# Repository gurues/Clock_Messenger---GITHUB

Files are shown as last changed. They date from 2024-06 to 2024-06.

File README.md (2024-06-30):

# CLOCK MESSENGER

## Descripción y funcionamiento

Clock Messenger es un pequeño proyecto que mediante un Wemos D1 mini, una matriz led MAX-7219 FC-16 y un buzzer se crea un dispositivo que mostrará la hora y mensajes básicos repetitivos de fecha y tiempo de la ciudad a elección. También se crea una app en Blynk 2.0 para controlar el dispositivo así como para enviar mensajes instantaneos, repetitivos o programados además de alarma sonora.

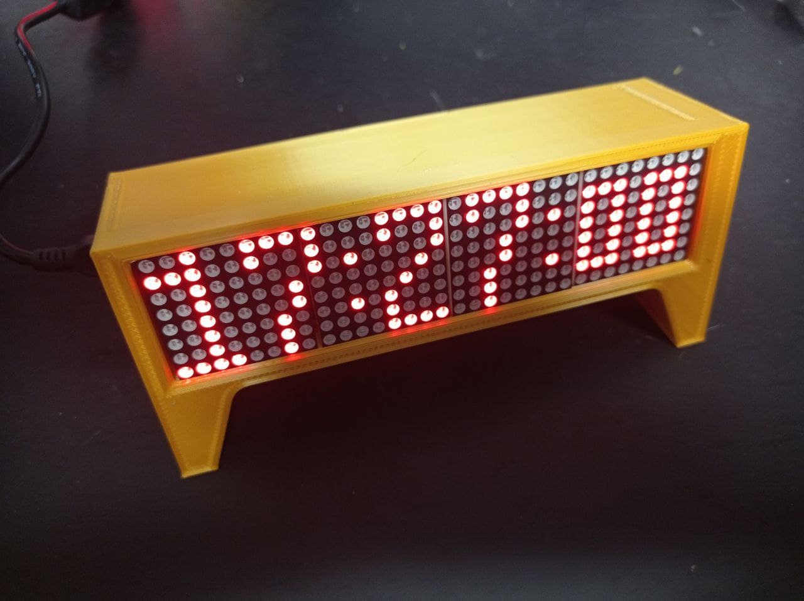
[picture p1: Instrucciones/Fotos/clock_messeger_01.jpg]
Clock Messenger


Debido a las restricciones de Blynk 2.0 (solo 5 DataStream en su versión libre) utilizaremos un terminal y una serie de comandos para configurar y controlar el Clock Messenger

Por lo tanto debes tener cuenta en Blynk y OpenWeatherMap para actualizar los siguientes parámetros:

main.cpp

```Arduino

// Actualizar con tus datos de BLYNK
#define BLYNK_TEMPLATE_ID "XXXXXXXXXXXXXXXXXX"
#define BLYNK_TEMPLATE_NAME "ClockMessenger"
#define BLYNK_AUTH_TOKEN "XXXXXXXXXXXXXXXXXXX"
```

configuracion.h

```Arduino
// Datos OpenWeatherMap
String hostOpenWeatherMap = "http://api.openweathermap.org/data/2.5/weather";

String apiKey = "XXXXXXXXXXXXXXXXXXXXXXXXXXXXX"; // Sustituye por tu API Key
String idCiudad = "XXXXXXXXXXXXX"; // Sustituye por el id de tu ciudad -> EJEMPLO: Cambrils = 3126888 Reus = 3111933.
```

Los mensajes tratados son:

* Mensajes de reloj. Muestran la hora en pantalla.
* Mensajes básicos. Muestras el tiempo de la ciudad configurada, día y fecha actual.
* Mensajes instantaneos. Enviados por la app de control.
* Mensajes repetitivos. Enviados y configurados por la app de control.
* Mensajes programados. Enviados y configurados por la app de control.

Para la configuración de los mensajes, estos deben comenzar de una forma determinada:

* Mensajes instantaneos: Deben comenzar por el caracter @. Ej: @Hola Mundo. Esto mostrará en la pantalla del reloj el mensaje Hola Mundo.
* Mensajes Repetitivos: Deben comenzar por el caracter R@. Ej: R@Hola Mundo. Esto mostrará en la pantalla del reloj el mensaje Hola Mundo de forma repetitiva
* Mensajes Programados: Deben comenzar por el caracter P@. Ej: P@Hola Mundo. Esto mostrará en la pantalla del reloj el mensaje Hola Mundo a la hora programada.

Disponemos de una serie de comandos que nos ayudaran configurar el dispositivo:

* Comando /MENSAJES/: Muestra los Mensajes Repetitivos y Programados configurados.
* Comando /HELP/: Muestra la Ayuda de comandos.
* Comando /parametro=: El numero después del = se configura como valor del parametro (ej: /offset=-3.5)
* Comando /parametro/: Muestra el valor actual del parametro de control (ej: /offset/)
* Comando /rep_min=: Configura los mensajes se repiten cada x minutos
* Comando /prog_h:min=: Configura hora del mensaje programado o de la alarma 1
* Comando /prog_h:min_2=: Configura hora de la alarma 2
* Comando /sonido=: Activa/Desactiva (1/0) mensajes con alerta sonora
* Comando /alarma=: Activada/Desactivada (1/0) Alarma sonora en Clock_Messenger
* Comando /offset=: Configura el offset de temperatura (ej: /OFFSET=-3.5)
* Comando /ESTADO/: Muestra el estado de los parametros de control Clock_Messenger
* Comando /CLEAR/: Limpia Terminal y vacia mensajes Repetitivos y Programados
  
Tanto los mensajes como los comandos se introduciran a través de la terninal de la aplicación de control del reloj (Blynk 2.0).

DataStream App control Clock Messenger (Blynk 2.0):

* V0. Control de tiempo del mensaje rodante en la pantalla (0 a 300 seg)
* V1. Terminal de control para la configuracón del Clock Messenger mediante comandos y mensajes.
* V2. Control de los mensajes programados (permisivo para la ejecución de mensajes programados)
* V3. Control de los mensajes repetitivos (permisivo para la ejecución de mensajes repetitivos)
* V4. Muestra en el Terminal todos los comandos de configuración del Clock Messenger

El funcionamiento de los mensajes es el siguiente:

* La priorida de los mensajes se determina por el orden de entrada o configuración. El último en entrar o configurarse es el que se muestra en pantalla y por lo tanto el más prioritario. Por eso los mensajes instantaneos son los más prioritarios. Respecto a la prioridad entre los mensajes repetitivos y programados se respeta la misma condición anterior, el último en entrar o configurarse se muestra en pantalla.

* Los mensajes de reloj y datos básicos son los menos prioritarios, siempre se detienen ante la llegada de los otros tipos de mensajes.

* Los mensajes se suceden a través de una serie de funciones hasta que se muestran en pantalla. El flujo de los mensajes y funciones se detalla a continuación:

```text
      retardo_messege() => Configura el tiempo total del mensaje en pantalla.

      send_message() => Envia y muestra el mensaje por pantalla.

      programador() => Controla retorno tras mostrar mensaje y activa las funciones de Clock 
                       y datos básicos.

      clock_send() => Muestra el reloj en pantalla.

      obtenerDatosBasicos() => Obtiene los datos básicos.

      envio_mensaje_rep() => Control de mensajes repetitivos.
```

* Flujo de mensajes instantaneos. Es el mensaje con mayor prioridad, detiene y muestra este mensaje en
  cuanto llegue frente a cualquier otro.

```text
      message = true ==>retardo_messege() -->send_message() -->programador()--> clock_send()

                                                                        |--> obtenerDatosBasicos()
```
  
* Flujo de mensajes programados. Son mensaje prioritarios al reloj y a los datos básicos. Si coinciden en el
  tiempo con estos se detienen y se mostraran los mensajes repetitivos.

```text
control_prog == 1(se cumple hh:mm) ==>retardo_messege() -->send_message() 
                                    
                                                             -->programador() -->clock_send()

                                                                        |--> obtenerDatosBasicos()
```

* Flujo de mensajes repetitivos. Son mensaje prioritarios al reloj y a los datos básicos. Si coinciden en el
  tiempo con estos se detienen y se mostraran los mensajes repetitivos.

```text
se programa tiempo repetición ==>envio_mensaje_rep() -->send_message() 
      
                                                            -->programador() -->clock_send()

                                                                        |--> obtenerDatosBasicos()
```

* El reloj se trata como si fuera un mensaje. Los mensajes de reloj son los menos prioritario.

```text
      clock_send() ==> Se ejecuta cada 1 seg para mostrar el reloj si no hay mensaje que mostrar

```

* Los mensajes de datos basicos se muestran de forma repetida y son los menos prioritarios junto al reloj.

```text  
obtenerDatosBasicos() ==> Se ejecuta cada 95 seg para mostrar el tiempo de la cuidad,el día y la fecha.

```

## Material necesario

* Wemos D1 Mini o ESP8266 NodeMCU.
* Matriz led MAX-7219 FC-16.
* Buzzer activo.
* Resistencia 220 ohm, transistor NPN y diodo (material opcional -> circuito para el contol del Buzzer).
* RTC DS3231 (opcional, solo si no se dispone de conexión permanete a internet).

## Instrucciones

La carpeta instrucciones hay una serie de guias y archivos que son de utilidad para realizar el proyecto.

* Carpeta 3D: Archivos STL o 3MF para la impresión de la caja del reloj.
* Carpeta Blynk: App de control de Clock Messenger.
* Carpeta Conexiones: Esquemas de conexiones del proyecto.
* Carpeta Fotos: Fotos del resultado final.

### No he encontrado el porque pero en unos 7 dias es necesario realizar un reset del reloj para que vuelva funcionar si utilizamos RTC. En tiendo que es un desbordamiento de algún registro pero no lo he podido solucionar. En la parte superior del reloj hay un agujero para que mediante un clip podamos acceder al reset del dispositivo
  
### Realizado por gurues@2024 (<ogurues@gmail.com>)

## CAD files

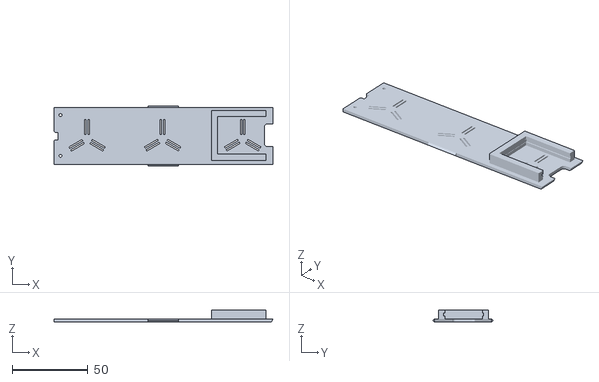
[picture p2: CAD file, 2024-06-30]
Instrucciones/3D/Box_Tapa_Clock_Messenger_WEMOS.stl
145.0 x 39.9 x 8.00

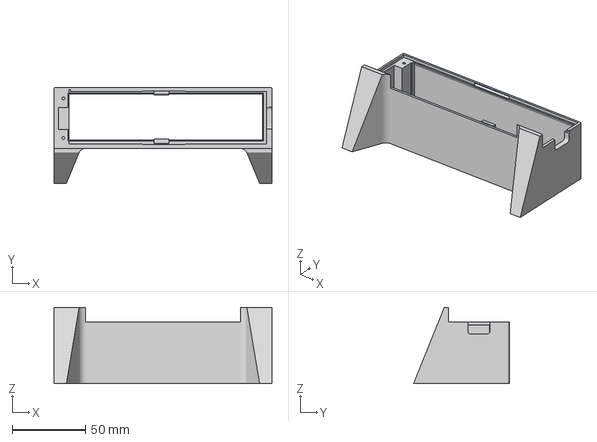
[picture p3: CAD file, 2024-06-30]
Instrucciones/3D/Box_Clock_Messenger.3mf
148.4 x 65.4 x 52.0 mm

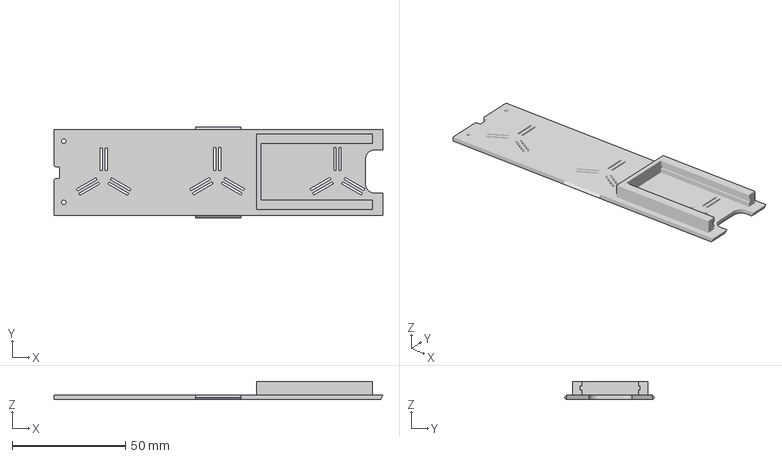
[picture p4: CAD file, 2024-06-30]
Instrucciones/3D/Box_Tapa_Clock_Messenger_ESP8266.3mf
145.0 x 39.9 x 8.00 mm

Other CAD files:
Instrucciones/3D/Caja_Clock_Messenger.3mf
Instrucciones/3D/Tapa_Clock_Messenger.3mf

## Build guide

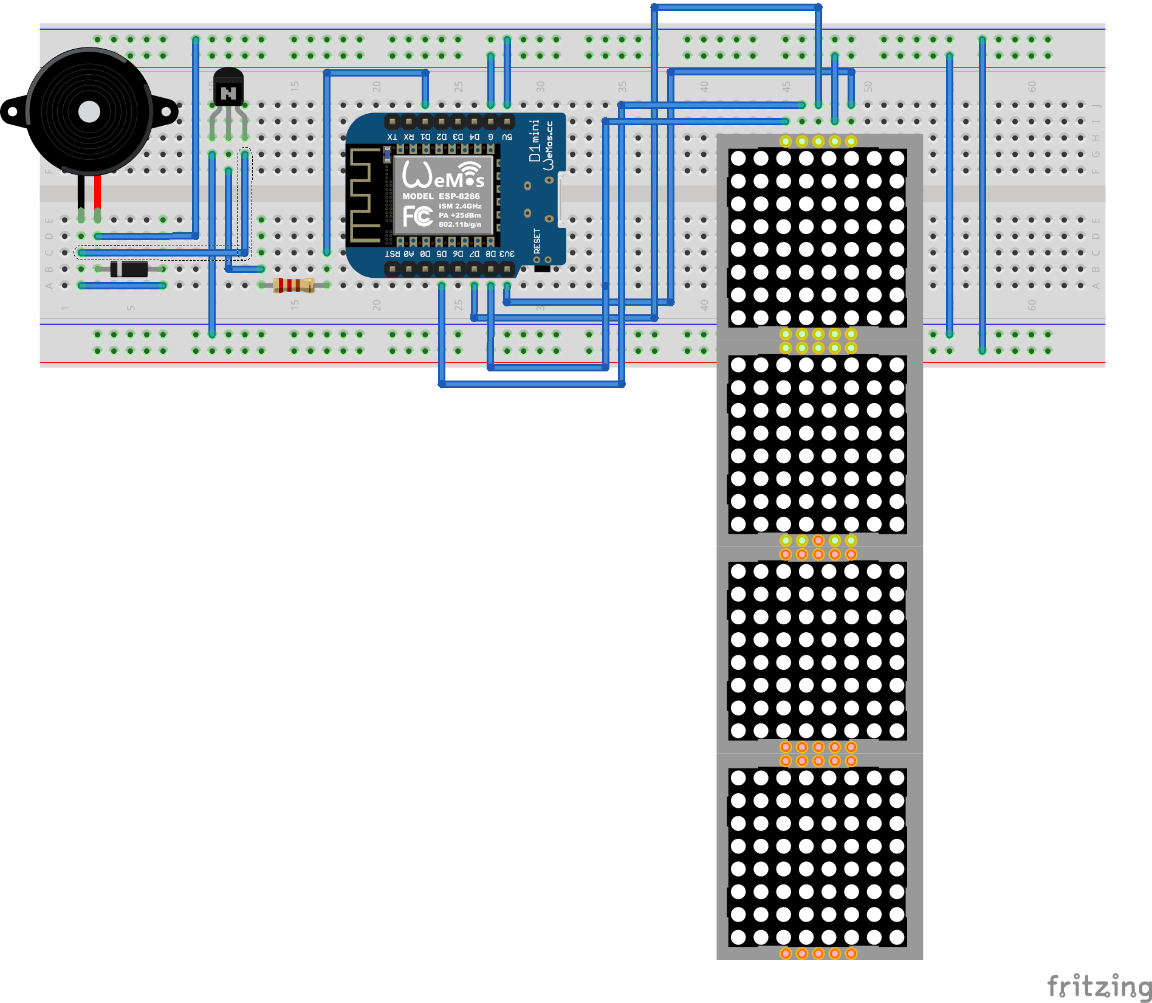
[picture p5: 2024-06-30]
Instrucciones/Conexiones/Clock_Messenger.png

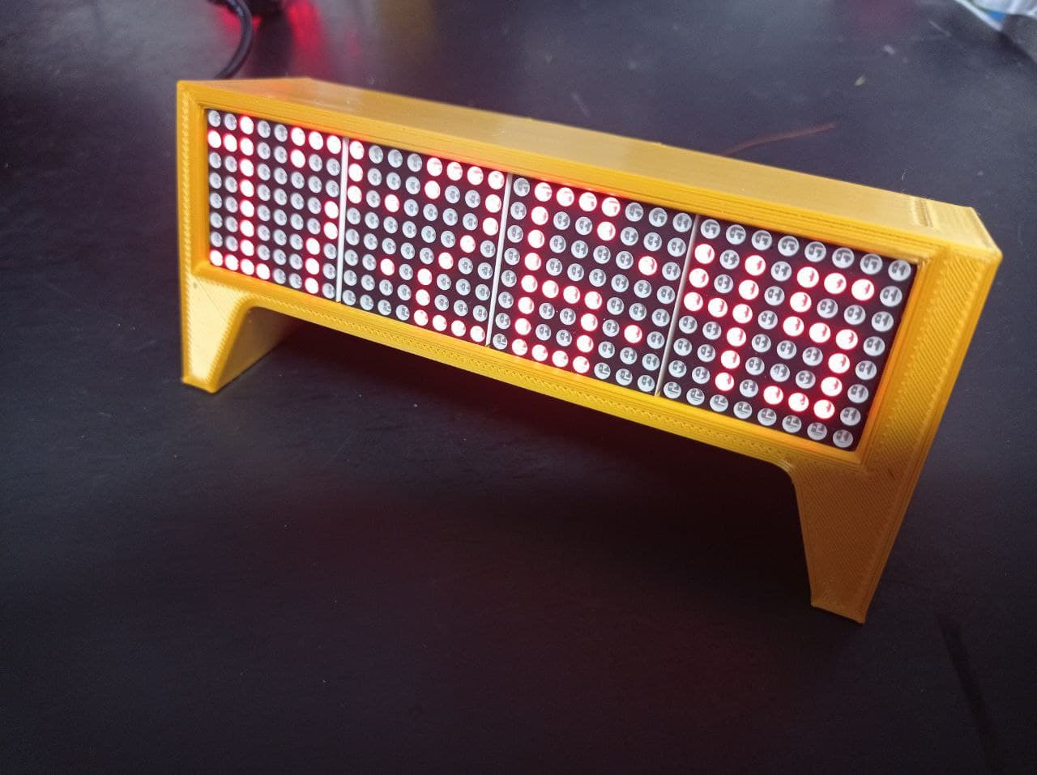
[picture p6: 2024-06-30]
Instrucciones/Fotos/clock_messeger_02.jpg

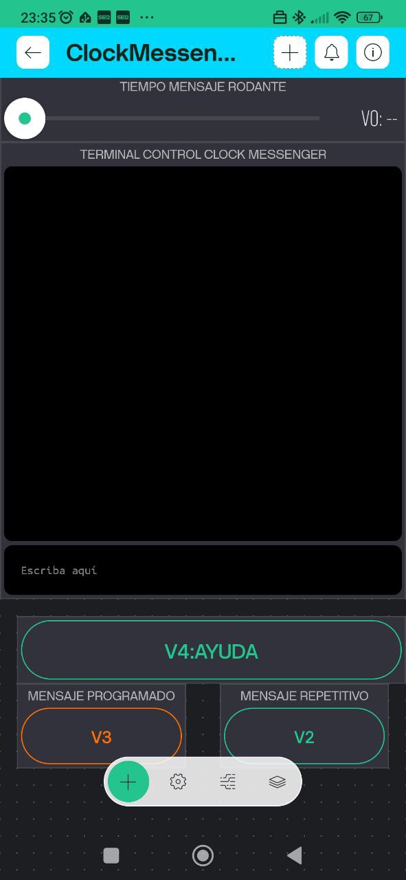
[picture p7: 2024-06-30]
Instrucciones/Blynk/app_1.jpg

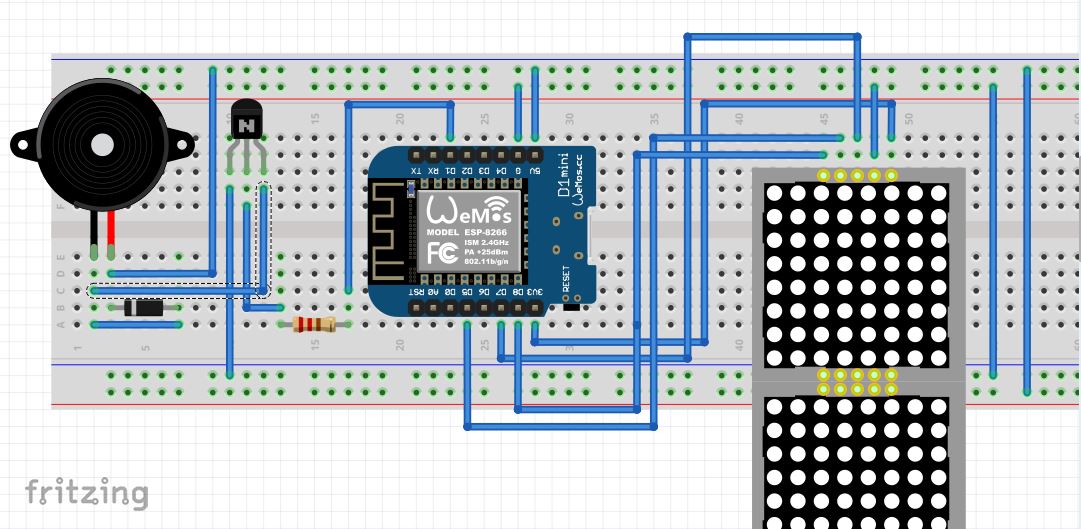
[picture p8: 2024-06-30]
Instrucciones/Conexiones/Conexiones Clock Messenger.JPG

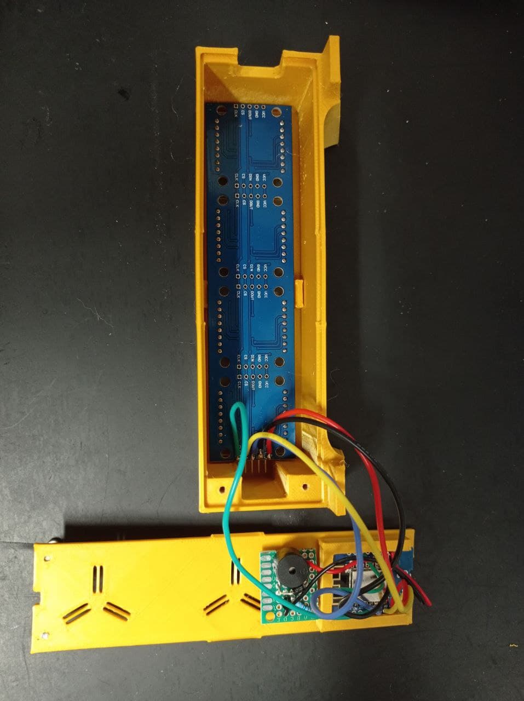
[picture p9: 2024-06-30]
Instrucciones/Fotos/clock_messeger_03.jpg

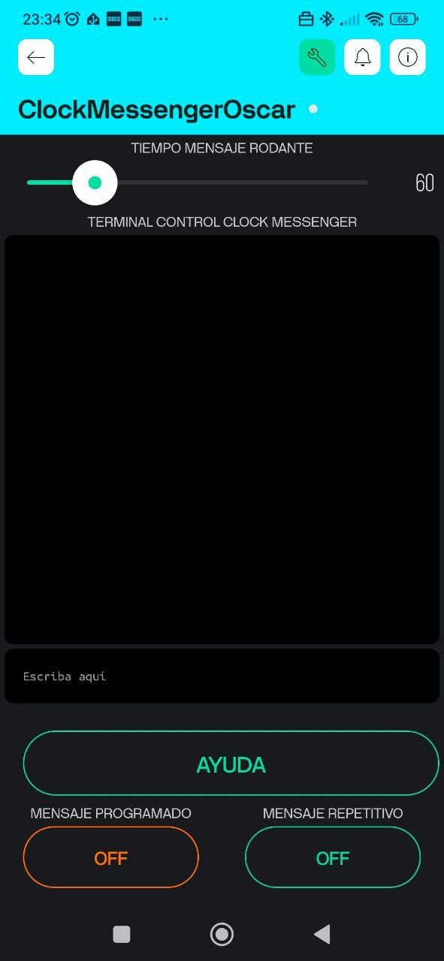
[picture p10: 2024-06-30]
Instrucciones/Blynk/app_2.jpg

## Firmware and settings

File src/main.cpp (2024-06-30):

/*  Realizdo por gurues@3DO 
-----------------------------------------------------------------------------------------------------------
-------------------------------         CLOCK MESSENGER         -------------------------------------------
-----------------------------------------------------------------------------------------------------------

  Mediante un Wemos D1 mini y una matriz led MAX-7219 FC-16 se realiza un dispositivo que mostrará la hora y
  mensajes básicos repetitivos de fecha y tiempo de la ciudad a elección. También se crea una app en Blynk
  para controlar el dispositivo así como para enviar mensajes instantaneos, repetitivos o programados. Solo
  con 5 DataStreams (restricción de Blynk)

***********************************************************************************************************
-- CONEXIÓN HARDWARE (Wemos D1 mini o ESP8266 <--> FC16):
-- 3V <--> VCC, GND <--> GND, D7 <--> DIN, D8 <--> CS, D5 <--> CLK
-- CONEXIÓN HARDWARE (Wemos D1 mini o ESP8266 <--> BUZZER):
-- D1 <--> - , GND, GND
-- Otra forma de conexión es mediante un transistor NPN
-- D1 Wemos/ESP <--> R1= 220 ohm, R1 <--> Base NPN, Emisor NPN <--> GND Wemos/ESP, Colector NPN <--> - Buzzer
-- + Buzzer <--> 5v Wemos/ESP, + diodo <--> - Buzzer, - diodo <--> + Buzzer
-- CONEXIÓN HARDWARE (Wemos D1 mini o ESP8266 <--> RTC -> DS3231):
-- D2, D3 <--> RTC -> DS3231 (si no disponemos conexión permanente a internet)
***********************************************************************************************************

*/

// Actualizar con tus datos de BLYNK
#define BLYNK_TEMPLATE_ID "XXXXXXXXXXXXXXXXXX"
#define BLYNK_TEMPLATE_NAME "ClockMessenger"
#define BLYNK_AUTH_TOKEN "XXXXXXXXXXXXXXXXXXX"

#define BLYNK_FIRMWARE_VERSION  "1.0.0"

// Comentar para deshabilitar el Debug de Blynk
//#define BLYNK_PRINT Serial        // Defines the object that is used for printing
//#define BLYNK_DEBUG               // Optional, this enables more detailed prints

#include <Arduino.h>
#include <configuracion.h>          // Configuración de usuario
#include <LedControlSPIESP8266.h>   // Control display led MAX7219 FC-16
#include <FC16.h>                   // Control display led MAX7219 FC-16
#include <WifiUDP.h>                // sincro servidor NTP
#include <TimeLib.h>                // sincro servidor NTP
#include <Ticker.h>                 // Temporizador funciones asincronas
#include <ArduinoOTA.h>             // Actualización por OTA
#include <ESP8266mDNS.h>            // Actualización por OTA
#include <BlynkSimpleEsp8266.h>     // Control externo mediante app
#include <ESP8266HTTPClient.h>      // openweathermap
#include <ArduinoJson.h>            // openweathermap
#include <DNSServer.h>              // Genera portal cautivo para configurar la wifi y variables
#include <ESP8266WebServer.h>       // Genera portal cautivo para configurar la wifi y variables
#include <WiFiManager.h>            // Genera portal cautivo para configurar la wifi y variables
#include <EasyBuzzer.h>             // Buzzer activo 
#ifdef ___RTC___
  #include <Wire.h>                   // RTC clock DS1307 y DS3231
  #include <RTClib.h>                 // RTC clock DS1307 y DS3231
#endif

// Configura el cliente NTP UDP
WiFiUDP ntpUDP;
unsigned int localPort = 8888;      // local port to listen for UDP packets
const int NTP_PACKET_SIZE = 48;     // NTP time is in the first 48 bytes of message
byte packetBuffer[NTP_PACKET_SIZE]; //buffer to hold incoming & outgoing packets

// NTP Servers:
//static const char ntpServerName[] = "pool.ntp.org";
//static const char ntpServerName[] = "es.pool.ntp.org";
static const char ntpServerName[] = "ntp.roa.es";

time_t prevDisplay = 0; // variable con la fecha Y hora a mostrar
time_t getNtpTime();
void sendNTPpacket(IPAddress &address);
bool sincronizado = false;   // variable de control primera sincronización

// Cliente web
HTTPClient clienteHttp;

// Cliente WIFI
WiFiClient clienteWIFI;

//Configurar LED MAC7219
const int csPin = D8;						          // CS pin used to connect FC16
const int displayCount = 4;			          // Number of displays; usually 4 or 8
FC16 display = FC16(csPin, displayCount);	// Define display parameters

//Configurar Buzzer
const int BuzzerPin = D1;                 // Pin del Buzzer activo de sonido

#ifdef ___RTC___
  //Configurar RTC DS1307 y DS3231
  const int PIN_SDA = D3;                   // Pin SCA I2C -> pin D3 shield D1 RTC1307
  const int PIN_SCL = D2;                   // Pin SCL I2C -> pin D2 shield D2 RTC1307

  RTC_DS3231 rtc;
  DateTime ahora;                           // hora RTC
#endif

//Variables grabales de control del programa
//Week Days
String weekDays[7] = {"Domingo", "Lunes", "Martes", "Miercoles", "Jueves", "Viernes", "Sabado"};
//Month names
String months[12]={"Enero", "Febrero", "Marzo", "Abril", "Mayo", "Junio", "Julio", "Agosto", "Septiembre", "Octubre", "Noviembre", "Diciembre"};

int currentHour, currentMinute, currentSecond;  // variables del mensaje clock
String Mensajes, Men_rep, Men_pro;              // variables Mensajes instantaneo, repetitivo y programado
bool message = false;                           // control de mensajes
bool control_instant = false;                   // control instantaneo
int sincro_rep = 0;                             // sincronizo el ticker de mensajes repetitivos
int control_rep = 0;                            // control de mensajes repetitivos app Blink
int rep_min = 60;                               // tiempo en segundos entre mensajes repetitivos app Blink
int control_prog = 0;                           // control de mensajes programados app Blink
int prog_hora = 14;                             // hora del mensaje programado y alarma 1 = 14:28
int prog_min = 28;                              // minuto del mensaje programado y alarma 1
int prog_hora2 = 16;                            // hora alarma 2 = 16:02
int prog_min2 = 2;                              // minuto alarma 2
int delayMensajes = 120;                        // tiempo de muestreo de mensajes rodantes
int memdelayMensajes = delayMensajes;           // memoria tiempo de muestreo de mensajes rodantes
int timeZone = 10;                              // Adelanto horario respecto hora solar se actualiza en la funcion obtenerDatosBasicos()
int sonido = 0;                                 // control de aviso por sonido de la llegada de mensajes
int alarma = 0;                                 // alarma programada
float offset = -4;                              // offset de temperatura
bool conect_wifi = false;                       // estado de conexión del clock messenger
String overTheAirURL = "";                      // URL para OTA desde Blynk

// Programadores de eventos Ticker
Ticker ticker_Datos, ticker_retardo_message, ticker_Clock,
        ticker_programador, ticker_mensaje_rep, ticker_mensaje_prog, 
        ticker_delay_60, ticker_delay_prog_60; 


/////////////////////////////////////////////////////////////////////////////////
//           FUNCIONES
/////////////////////////////////////////////////////////////////////////////////

// Control retraso mensajes con app Blink
BLYNK_WRITE(V0){                //-> se auto sicronizar Blynk app
  delayMensajes = param.asInt();
  memdelayMensajes = delayMensajes;
  #ifdef ___DEBUG___
    Serial.print("delayMensajes = ");
    Serial.println(delayMensajes);
  #endif
}

// Terminal - Control de Clock Messenger con app Blink 
WidgetTerminal terminal(V1);  // No se auto sicronizar Blynk app
BLYNK_WRITE(V1){
  Blynk.syncVirtual(V0);
  String Men = param.asStr();

  // Muestra los comandos de control de la app Blynk
  if (Men == "/HELP/"){
    terminal.clear();
    terminal.println("");
    terminal.println("/HELP/: Muestra la Ayuda de comandos");
    terminal.println("Mensajes Instantaneos comienzan por: @ ");
    terminal.println("Mensajes Repetitivos comienzan por: R@ ");
    terminal.println("Mensajes Programados comienzan por: P@ ");
    terminal.println("/MENSAJES/: Muestra los Mensajes Repetitivos y Programados configurados");
    terminal.println("/parametro=: El numero después del = se configura como valor del parametro (ej: /offset=-3.5)");
    terminal.println("/parametro/: Muestra el valor actual del parametro de control (ej: /offset/)");
    terminal.println("/rep_min=: Configura los mensajes se repiten cada x minutos");
    terminal.println("/prog_h:min=: Configura hora del mensaje programado o de la alarma");
    terminal.println("/prog_h:min_2=: Configura hora de la alarma 2");
    terminal.println("/sonido=: Activa/Desactiva (1/0) mensajes con alerta sonora");
    terminal.println("/alarma=: Activada/Desactivada (1/0) Alarma sonora en Clock_Messenger");
    #ifdef ___RTC___
      terminal.println("/offset=: Configura el offset de temperatura (ej: /OFFSET=-3.5)");
    #endif
    terminal.println("/ESTADO/: Muestra el estado de los parametros de control Clock_Messenger");
    terminal.println("/CLEAR/: Limpia Terminal y vacia mensajes Repetitivos y Programados");
    terminal.flush();
  }

  // Se evalua el mensaje a enviar: instantaneo, repetitivo, programado
  if (Men.substring(0, 1) == "@"){  // instantaneo
    Mensajes = Men.substring(1, Men.length());
    message = true;
    control_instant = true;
  }
  if (Men.substring(0, 2) == "R@"){  // repetitivo
    Blynk.virtualWrite(V2, 0);
    control_rep = 0;
    Men_rep = Men.substring(2, Men.length());
    control_instant = false;
  }
  if (Men.substring(0, 2) == "P@"){  // programado
    Blynk.virtualWrite(V3, 0);
    control_prog = 0;
    Men_pro = Men.substring(2, Men.length());
    control_instant = false;
  }
  
  // Información de los mensajes configurados
  if (Men == "/MENSAJES/"){
    terminal.println("Mensaje Repetitivo: R@ ");
    terminal.println(Men_rep);
    terminal.println("Mensajes Programado: P@ ");
    terminal.println(Men_pro);
    terminal.flush();
  }

  // Control de mensajes con repetición
  if (Men == "/rep_min/"){
      terminal.print("Los mensajes se repiten cada ");
      terminal.print(rep_min/60);
      terminal.println(" minutos");
      terminal.flush();
  }
  if (Men.substring(0, 9) == "/rep_min="){
    rep_min = Men.substring(9, Men.length()).toFloat();
    rep_min = rep_min*60;
    terminal.println(" ");
    terminal.print("Actualizado rep_min a ");
    terminal.print(rep_min/60);
    terminal.println(" minutos");
    terminal.flush();
  }

  // Control alerta sonora mensajes 
  if (Men == "/sonido/"){
    if (sonido==1){
      terminal.println(" ");
      terminal.println("Activado mensajes con alerta sonora en Clock_Messenger");
      terminal.flush();
    }
    if (sonido==0){
      terminal.println(" ");
      terminal.println("Desactivados mensajes con alerta sonora en Clock_Messenger");
      terminal.flush();
    }
  }
  if (Men.substring(0, 8) == "/sonido="){
    sonido = Men.substring(8, Men.length()).toFloat();
    if (sonido==1){
      terminal.println(" ");
      terminal.println("Activado mensajes con alerta sonora en Clock_Messenger");
      terminal.flush();
    }
    if (sonido==0){
      terminal.println(" ");
      terminal.println("Desactivados mensajes con alerta sonora en Clock_Messenger");
      terminal.flush();
    }
  }

  // Control alarma
  if (Men == "/alarma/"){
    if (alarma==1){
      terminal.println(" ");
      terminal.println("Activada Alarma sonora en Clock_Messenger");
      terminal.flush();
    }
    if (alarma==0){
      terminal.println(" ");
      terminal.println("Desactivada Alarma Sonora en Clock_Messenger");
      terminal.flush();
    }
  }
  if (Men.substring(0, 8) == "/alarma="){
    alarma = Men.substring(8, Men.length()).toFloat();
    if (alarma==1){
      terminal.println(" ");
      terminal.println("Activada Alarma sonora en Clock_Messenger");
      terminal.flush();
    }
    if (alarma==0){
      ticker_delay_60.detach();
      terminal.println(" ");
      terminal.println("Desactivada Alarma Sonora en Clock_Messenger");
      terminal.flush();
    }
  }

  // Control mensajes programados y alarma 1
  if (Men == "/prog_h:min/"){
    terminal.print("Hora Programada ");
    terminal.print(prog_hora);
    terminal.print(":");
    if(prog_min<10)
    terminal.print("0");
    terminal.print(prog_min);
    terminal.println("h");
    terminal.flush();
  }
  if (Men.substring(0, 12) == "/prog_h:min="){
    prog_hora = Men.substring(12, 15).toInt();
    prog_min = Men.substring(15, Men.length()).toInt();
    terminal.println(" ");
    terminal.print("Hora Programada: ");
    terminal.print(prog_hora);
    terminal.print(":");
    if(prog_min<10)
      terminal.print("0");
    terminal.print(prog_min);
    terminal.println("h");
    terminal.flush();
  }

  // Control alarma 2
  if (Men == "/prog_h:min_2/"){
    terminal.print("Hora Programada alarma 2: ");
    terminal.print(prog_hora2);
    terminal.print(":");
    if(prog_min2<10)
      terminal.print("0");
    terminal.print(prog_min2);
    terminal.println("h");
    terminal.flush();
  }
  if (Men.substring(0, 14) == "/prog_h:min_2="){
    prog_hora2 = Men.substring(14, 17).toInt();
    prog_min2 = Men.substring(17, Men.length()).toInt();
    terminal.println(" ");
    terminal.print("Hora Programada Alarma 2: ");
    terminal.print(prog_hora2);
    terminal.print(":");
    if(prog_min<10)
      terminal.print("0");
    terminal.print(prog_min2);
    terminal.println("h");
    terminal.flush();
  }

  // Control ajuste temperatura RTC
  #ifdef ___RTC___
    if (Men == "/offset/"){
      terminal.print("offset de temperatura =");
      terminal.println(offset);
      float temp = rtc.getTemperature() + offset;
      terminal.println("Temperatura = " + String(temp) + "ºC");
      terminal.flush();
    }

    if (Men.substring(0, 8) == "/offset="){
      offset = Men.substring(8, Men.length()).toFloat();
      terminal.println(" ");
      terminal.print("Actualizado offset de temperatura =");
      terminal.println(offset);
      float temp = rtc.getTemperature() + offset;
      terminal.println("Temperatura = " + String(temp) + "ºC");
      terminal.flush();
    }
  #endif

  // Muestra el estado de configuración del Clock_Messenger
  if (Men == "/ESTADO/"){
    //mensajes
    terminal.println("Mensaje Repetitivo: R@ ");
    terminal.println(Men_rep);
    terminal.println("Mensajes Programado: P@ ");
    terminal.println(Men_pro);
    // rep_min - mensajes repetidos
    terminal.print("Los mensajes se repiten cada ");
    terminal.print(rep_min/60);
    terminal.println(" minutos");
    //sonido
    if (sonido==1)
      terminal.println("Activado mensajes con alerta sonora en Clock_Messenger");
    if (sonido==0)
      terminal.println("Desactivados mensajes con alerta sonora en Clock_Messenger");
    //alarma
    if (alarma==1)
      terminal.println("Activada Alarma sonora en Clock_Messenger");
    if (alarma==0)
      terminal.println("Desactivada Alarma Sonora en Clock_Messenger");
    //hora prog y alarma 1
    terminal.print("Hora Programada alarma: ");
    terminal.print(prog_hora);
    terminal.print(":");
    if(prog_min<10)
    terminal.print("0");
    terminal.print(prog_min);
    terminal.println("h");
    //hora prog y alarma 2
    terminal.print("Hora Programada alarma 2: ");
    terminal.print(prog_hora2);
    terminal.print(":");
    if(prog_min2<10)
      terminal.print("0");
    terminal.print(prog_min2);
    terminal.println("h");
    // Offset de temperatura
    #ifdef ___RTC___
      terminal.print("offset de temperatura =");
      terminal.println(offset);
      float temp = rtc.getTemperature() + offset;
      terminal.println("Temperatura = " + String(temp) + "ºC");
    #endif

    terminal.flush();

  }

  // Borrado del Terminal y borrado de mensajes programados y repetitivos
  if (Men == "/CLEAR/"){
    terminal.clear();         
    Men_pro = "";
    Men_rep = "";
    ticker_mensaje_rep.detach();
    ticker_mensaje_prog.detach();
    control_rep = 0;
    control_prog = 0;
    Blynk.virtualWrite(V2,control_rep);
    Blynk.virtualWrite(V3,control_prog);
    Blynk.syncVirtual(V2,V3);
    terminal.println(" ");
    terminal.println("Limpiado Terminal del Clock_Messenger");
    terminal.println("Se han vaciado los mensajes Repetitivos y Programados del Clock_Messenger");
    terminal.flush();
  }

} // Fin de control Terminal V1

// control mensajes repetitivos -> se auto sicronizar Blynk app
BLYNK_WRITE(V2){          
  Blynk.syncVirtual(V0);
  control_rep = param.asInt();
  sincro_rep = 1;
  if ((control_rep == 1)&&(Men_rep=="")){
    terminal.println(" ");
    terminal.println("Mensaje repetitivo vacio, inserta un mensaje repetitivo, R@");
    terminal.flush();
  }
  if ((control_rep == 1)&&(Men_rep!="")){
    terminal.println(" ");
    terminal.println("Activados Mensajes repetitivos en Clock_Messenger");
    terminal.flush();
  }
  if (control_rep == 0){
    terminal.println(" ");
    terminal.println("Desactivados Mensajes repetitivos en Clock_Messenger");
    terminal.flush();
  }
}
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
void loop() {

  if (WiFi.status() == WL_CONNECTED){
    ArduinoOTA.handle();    // Actualización código por OTA
    Blynk.run();            // Actualización app Blynk -> Si viene de una desconexión wifi también conecta a Blynk
    conect_wifi = true;
  }

  EasyBuzzer.update();  // Actualización Buzzer

  if (sincronizado){
    // Actualizar y sincronizar hora y fecha del servidor NTP con WIFI
    if ((timeStatus() != timeNotSet) && (WiFi.status() == WL_CONNECTED)){
      if (now() != prevDisplay) { //actualiza el display solo si el tiempo ha cambiado
        prevDisplay = now();
        currentHour = hour(prevDisplay);            // retorna horas -> time t
        currentMinute = minute(prevDisplay);        // retorna minutos -> time t
        currentSecond = second(prevDisplay);        // retorna segundos -> time t
        #ifdef ___RTC___
          //Ajusto RTC con los valores del servidor NTP
          rtc.adjust(DateTime(year(), month(), 
                                  day(), hour(), 
                                  minute(), second())
                            );
          // Verificar RTC
          // WiFi.mode(WIFI_OFF);
          // Serial.println("------------ Desconectado red WIFI ------------ ");
        #endif
      }
      conect_wifi = true;
    }

    #ifdef ___RTC___
      // Actualizar y sincronizar hora y fecha del RTC sin WIFI
      if (WiFi.status() != WL_CONNECTED){
        ahora = rtc.now();                    // fecha y hora actual
        currentSecond = ahora.second();       // retorna segundos -> time t
        currentMinute = ahora.minute();       // retorna minutos -> time t
        currentHour = ahora.hour();           // retorna horas -> time t
        conect_wifi = false;
      }
    #endif
    
    display.update();
    delay(scrollDelay);

    // Envio de mesajes intantaneos por Blink o configurados internamente (básicos y clock)
    if (message){
      retardo_messege();
      send_message();
    }

    // Mensajes Programados
    if ((control_prog == 1)&&(currentHour == prog_hora) && (currentMinute == prog_min)){
      ticker_mensaje_rep.detach();  // detengo mensajes repetitivos
      Mensajes = Men_pro;
      control_prog = 0;
      retardo_messege();
      send_message();
      ticker_delay_prog_60.once_scheduled(65, Act_prog);
      if (control_rep == 1)
          ticker_mensaje_rep.attach_scheduled(rep_min,envio_mensaje_rep);
    } 

    // Mensajes repetitivos
    if ((control_rep == 1)&&(sincro_rep==1)){
      #ifdef ___DEBUG___
        Serial.println("Activados Mensajes Repetitivos");
      #endif
      sincro_rep = 0;
      ticker_mensaje_rep.attach_scheduled(rep_min,envio_mensaje_rep);
    }
    if ((control_rep == 0)&&(sincro_rep==1)){
      #ifdef ___DEBUG___
        Serial.println("Desactivados Mensajes Repetitivos");
      #endif
      sincro_rep = 0;
      ticker_mensaje_rep.detach();
    }

    // Alarma programada_1
    if ((alarma == 1)&&(currentHour == prog_hora) && (currentMinute == prog_min)){
      ticker_mensaje_rep.detach();
      EasyBuzzer.beep(a_frequency, a_onDuration, a_offDuration, a_beeps, a_pauseDuration, a_cycles);
      if (control_rep == 1)
        ticker_mensaje_rep.attach_scheduled(rep_min,envio_mensaje_rep);
      alarma = 0;
      ticker_delay_60.once_scheduled(65, AlarmaON);
    }
    // Alarma programada_2
    if ((alarma == 1)&&(currentHour == prog_hora2) && (currentMinute == prog_min2)){
      ticker_mensaje_rep.detach();
      EasyBuzzer.beep(a_frequency, a_onDuration, a_offDuration, a_beeps, a_pauseDuration, a_cycles);
      if (control_rep == 1)
        ticker_mensaje_rep.attach_scheduled(rep_min,envio_mensaje_rep);
      alarma = 0;
      ticker_delay_60.once_scheduled(65, AlarmaON);
    }

    // No se programa mensaje repetitivo si está vacio
    if ((control_rep == 1)&&(Men_rep=="")){
      control_rep =0;
      Blynk.virtualWrite(V2,control_rep);
      ticker_mensaje_rep.detach();
      #ifdef ___DEBUG___
        Serial.println("Desactivados Mensajes Repetitivos");
      #endif
    }
      
    // No se programa mensaje programado si está vacio
    if ((control_prog == 1)&&(Men_pro=="")){
      control_prog =0;
      Blynk.virtualWrite(V3,control_prog);
      #ifdef ___DEBUG___
        Serial.println("Desactivados Mensajes Programados");
      #endif
    }

  }
  else{
    // Inicializo datos basicos -> actualizar timeZone
    // hasta que se sincronice
    obtenerDatosBasicos();    
    if (timeZone!=10){
      // Servidor NTP
      ntpUDP.begin(localPort);
      setSyncProvider(getNtpTime);
      setSyncInterval(sincro_Clock);
    }
  }

}

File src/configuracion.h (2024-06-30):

#pragma once

#include <ESP8266WiFi.h>

//Descomenta para usar DEBUG por puerto serie
//#define ___DEBUG___
//Descomenta para usar DEBUG1 por puerto serie (Muestra la hora)
//#define ___DEBUG1___

//Descomentar si en Clock_Messenger tiene RTC hardware
#define ___RTC___

const char *hostname = "Clock_Messenger";

// Comenta la siguiente linea para que la IP sea otorgada por el DHCP de tu router
//#define ip_fija

#ifdef ip_fija
    IPAddress ip(192, 168, 1, 161); // Modificar en platformio.ini si se cambia la IP
    IPAddress gateway(192,168,1,1);
    IPAddress subnet (255,255,255,0);
    IPAddress dns1(192,168,1,1);
#endif

// Datos OpenWeatherMap
String hostOpenWeatherMap = "http://api.openweathermap.org/data/2.5/weather";

String apiKey = "XXXXXXXXXXXXXXXXXXXXXXXXXXXXX";    // Sustituye por tu API Key
String idCiudad = "XXXXXXXXXXXXX";                  // Sustituye por el id de tu ciudad -> EJEMPLO: Cambrils = 3126888 Reus = 3111933
             
        
// Parametros constantes a definir por el usuario
const int intensidad = 1;                 // intensidad billo leds
const int offsetdisplay = 0;              // permite compensar la visualización por un número de columnas
const int sincro_Clock = 1800;            // cada X segundos se sincornizar fecha y hora
const int scrollDelay = 100;              // pausa entre rotaciones del mensaje en ms
const int time_data = 600;                // 600 segundos para actualizar los datos basicos, fecha y openweathermap
const int retardoBasico = 120;            // Tiempo en seg de scrolling datos basicos, fecha y openweathermap
const unsigned int frequency = 1500;      // frecuencia del pitido que reproducirá el zumbador o buzzer
const unsigned int onDuration = 500;      // duración del sonido del beep en milisegundos
const unsigned int offDuration = 300;     // duración del silencio del beep en milisegundos
const unsigned int beeps = 2;             // número de pitidos
const unsigned int pauseDuration = 200;   // duración de la pausa entre los diferentes beeps
const unsigned int cycles = 1;            // número de veces que se repiten los números de beeps
const unsigned int a_frequency = 1900;    // frecuencia del pitido que reproducirá el zumbador o buzzer
const unsigned int a_onDuration = 500;    // duración del sonido del beep en milisegundos
const unsigned int a_offDuration = 300;   // duración del silencio del beep en milisegundos
const unsigned int a_beeps = 5;           // número de pitidos
const unsigned int a_pauseDuration = 200; // duración de la pausa entre los diferentes beeps
const unsigned int a_cycles = 4;          // número de veces que se repiten los números de beeps
